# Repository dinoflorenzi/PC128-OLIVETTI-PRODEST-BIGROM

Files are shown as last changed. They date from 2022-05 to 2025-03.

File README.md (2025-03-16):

# PC128-OLIVETTI-PRODEST-BIGROM
## PROJECT OVERVIEW
Questo è un progetto nato per realizzare una cartuccia rom multi pagina per il mio PC 128 OLIVETTI PRODEST HOME COMPUTER.
Ho progettato e costruito due diverse schede ROM basate su due diversi chip ROM.
Una scheda ROM è basata sul chip rom at28c256, la seconda è basata sul chip flash sst39f040.
Inoltre ho codificato le routine ASM 6809 per gestirle.<br/>

## COME E' NATO IL PROGETTO
Molte sono le cartucce rom progettate, ma ho avuto la necessità di progettare la mia versione, con pochi semplici componenti e la possibilità di programmare la rom dal pc128 stesso, senza utilizzare strumenti di programmazione esterni.
Infatti, è possibile caricare l'immagine rom da masterizzare, utilizzando un dispositivo a cassetta o tramite connessione seriale a un PC esterno.<br/>
## PORTA PER CARTUCCE
I computer PC128 dispongono di una porta per cartucce con i segnali principali del computer, bus dati a 8 bit, bus indirizzi a 16 bit, chip select, master clock.<br/>
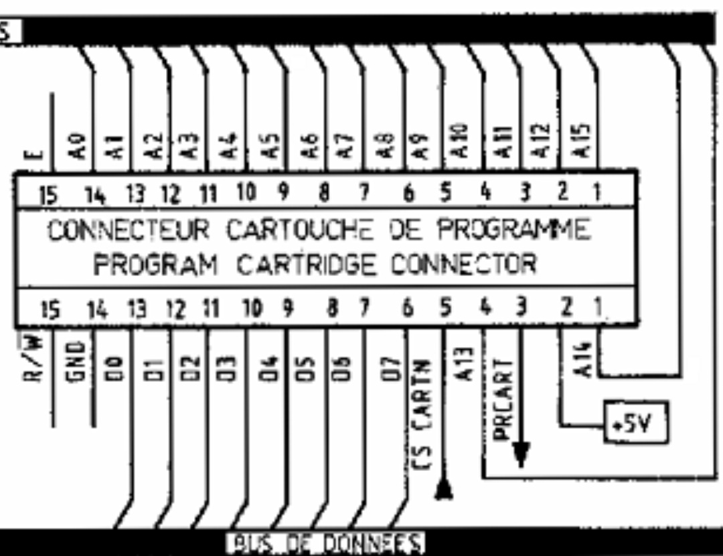
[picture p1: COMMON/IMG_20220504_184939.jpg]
<br/>
## SCELTA DELLE ROM CHIP
La prima selezione di chip AT28C256 si basa sulla sua architettura semplice, bus a 8 bit, indirizzo a 15 bit ed è molto semplice da programmare. Un altro buon motivo è che avevo 3 componenti di riserva nel mio cassetto :)
La selezione del secondo chip SST39F040 si basa anche sul suo package (DIP32), sulla tecnologia pth, sul bus a 8 bit, e soprattutto sulla sua dimensione di 512 kbyte che permette di commutare tra 32 pagine da 16 kbyte ciascuna.
Gli sviluppi della scheda singola sono meglio descritti nei link sottostanti o nella sezione wiki<br/>

[CARTUCCIA A PAGINA SINGOLA](https://github.com/dinoflorenzi/PC128-OLIVETTI-PRODEST-BIGROM/wiki/Single-Page-Rom)<br/>
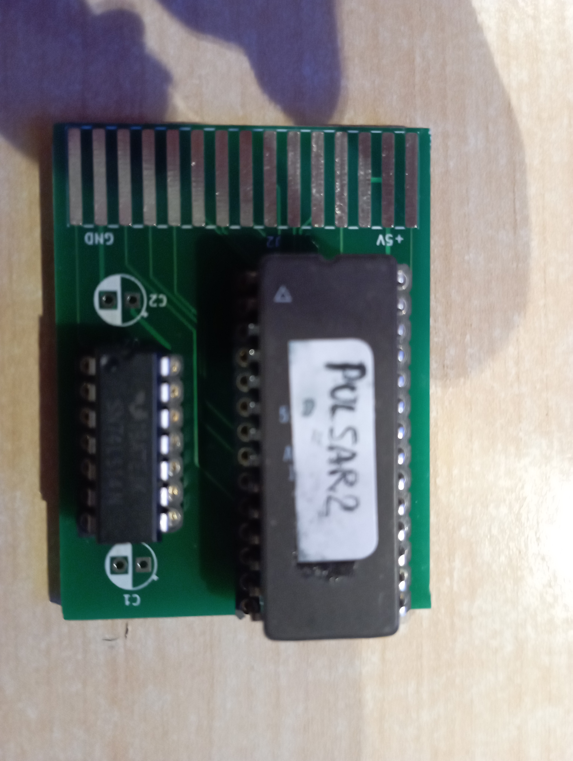
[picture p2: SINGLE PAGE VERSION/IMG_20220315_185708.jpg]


[BIGROM](https://github.com/dinoflorenzi/PC128-OLIVETTI-PRODEST-BIGROM/wiki/BigRom)<br/>
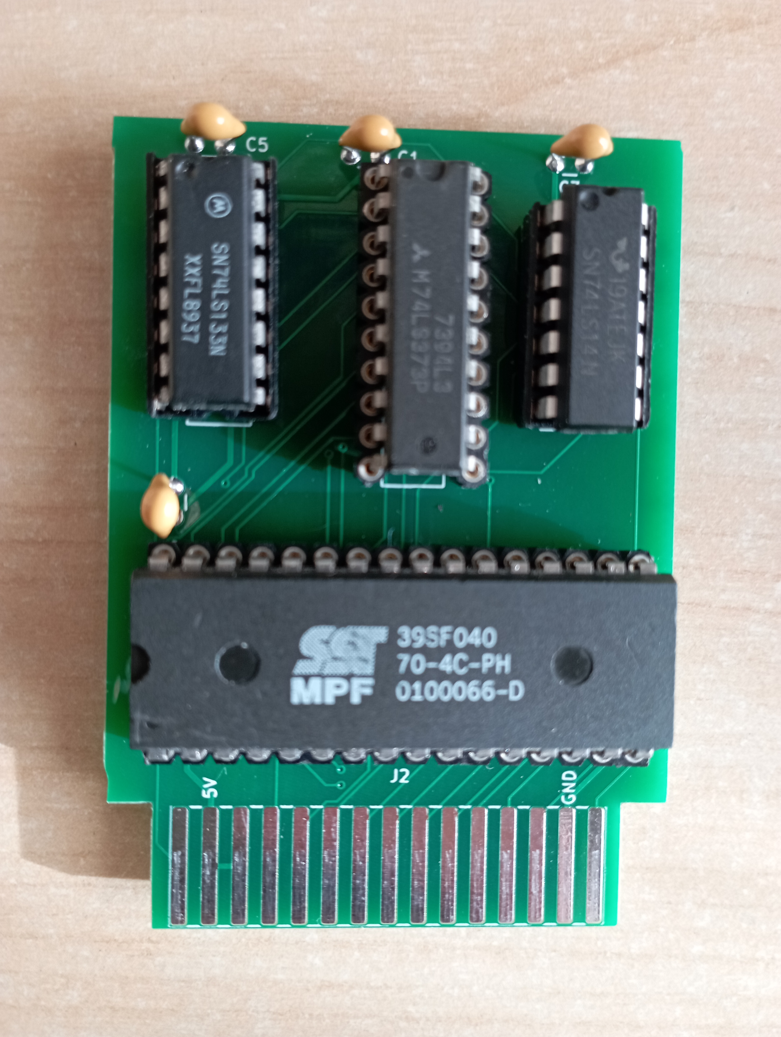
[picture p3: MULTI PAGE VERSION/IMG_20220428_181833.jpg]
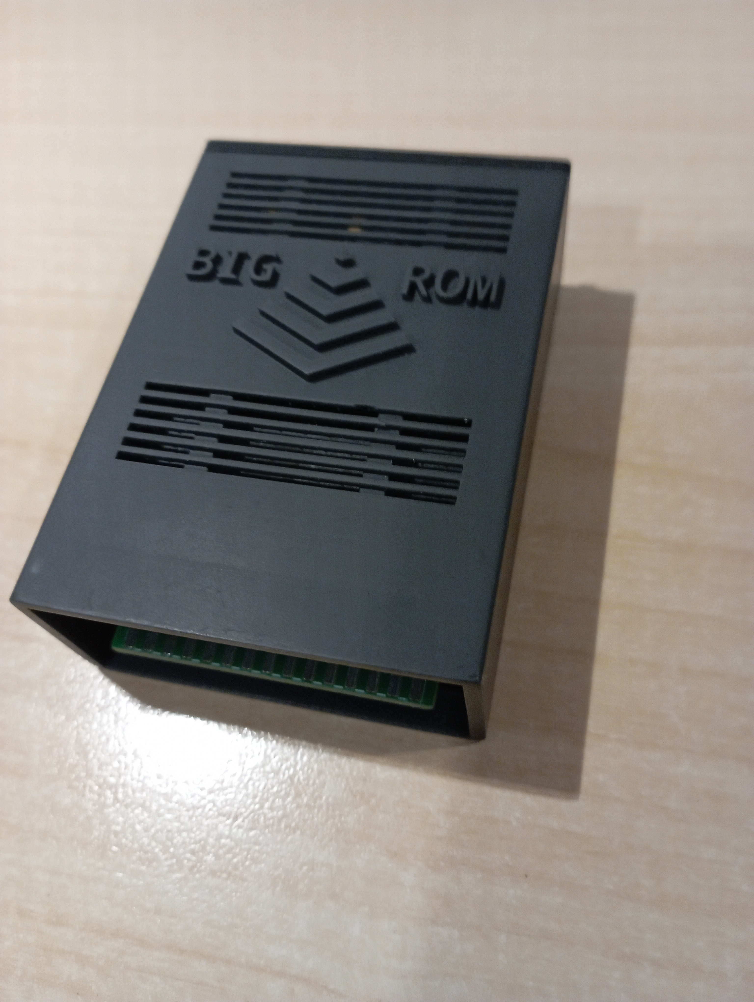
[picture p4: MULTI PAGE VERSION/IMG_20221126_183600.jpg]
 

### INSTALLAZIONE DELLA BIGROM
La cartuccia si installa nello sportellino centrale del PC128, a computer spento, come mostrato nella foto<br/>
Per l' installazione del software di gestione della bigrom è possibile utilizzare un programmatore utilizzando il file bigrom.eeprom, in tal caso la flash deve essere programmata prima dell' installazione sulla scheda. Altrimenti è possibile caricare il programma di gestione da registratore utilizzando un'audiocassetta su cui deve essere registrato il file audio bigrom.k7.wav. Dopodiché da basic 128 digitare<br/>
CLEAR,&H2FFF<br/>
LOADM"CASS:",,R<br/>
A questo punto sarà possibile caricare il file bigrom.rom in posizione V che è la posizione di boo.</br>
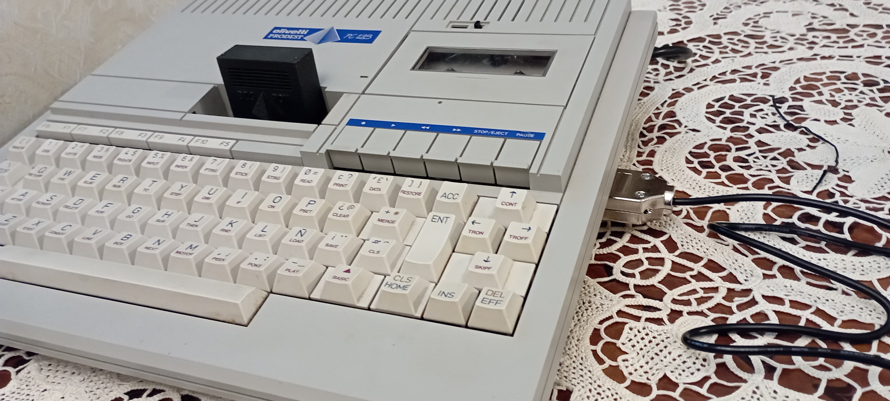
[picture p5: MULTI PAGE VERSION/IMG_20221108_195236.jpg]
<br/>

### FILE MANAGER DELLA BIGROM
Una delle 32 pagine della Bigrom è dedicata al programma di gestione della Bigrom stessa.
La schermata principale visualizza l'elenco dei programmi contenuti nella Bigrom. Basta premere il relativo tasto per scegliere la ROM.
Una volta avviata la ROM per tornare al programma BIGROM bisogna spegnere e riaccendere il computer.<br/>
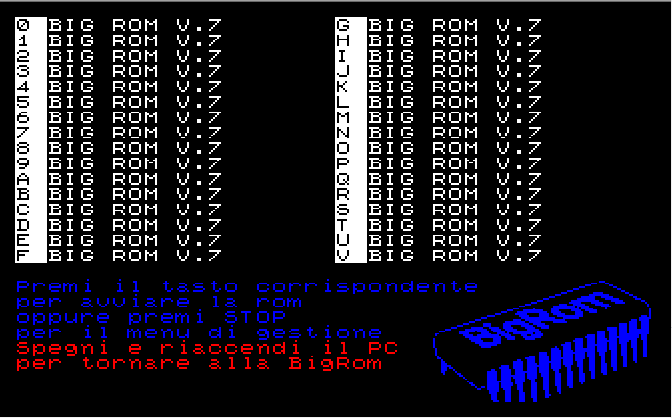
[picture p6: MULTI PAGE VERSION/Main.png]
<br/>
Premendo il tasto STOP dal menu di scelta delle ROMS si entra nel menu di gestione della ROM.<br/>
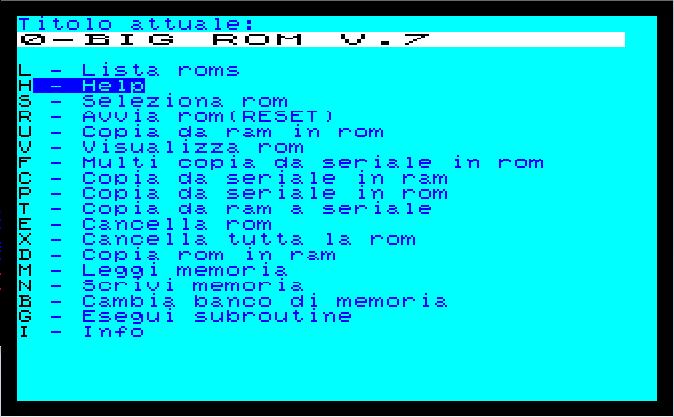
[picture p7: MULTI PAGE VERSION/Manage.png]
<br/>

### CONNESSIONE SERIALE
La connessione seriale sfrutta un UART-USB adapter, che connette il PC128 ad un computer con sistema opperativo windows.
Per il funzionamento del cavo seriale sarà necessario installare i [drivers](https://github.com/dinoflorenzi/PC128-OLIVETTI-PRODEST-BIGROM/tree/main/SERIAL-INTERFACE/Software/WIN_DRIVERS).<br/>E' consigliato l' utilizzo dell' interfaccia CH340 per un discorso di compatibilità.<br/>
Il [cavo](https://github.com/dinoflorenzi/PC128-OLIVETTI-PRODEST-BIGROM/wiki/Serial-Cable) si connette alla porta joystick 2 del PC128 e ad una qualsiasi porta USB del computer Windows.<br/>
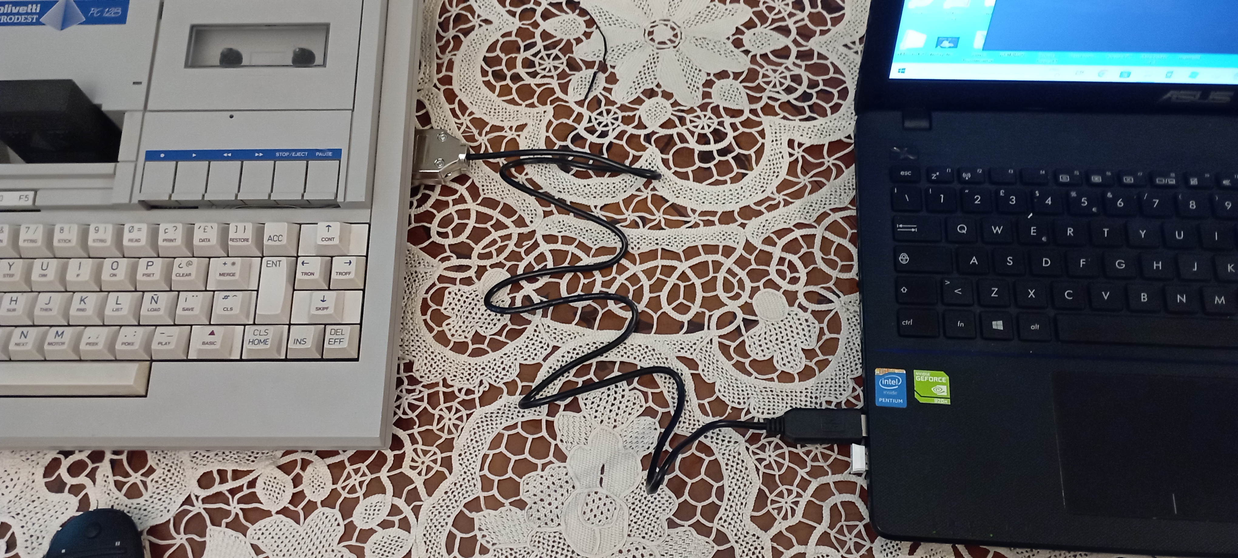
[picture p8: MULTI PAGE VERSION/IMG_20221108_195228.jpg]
<br/><br/>
Dal lato computer Windows si deve avviare il programma [VSerialRomT.exe](https://github.com/dinoflorenzi/PC128-OLIVETTI-PRODEST-BIGROM/blob/main/SERIAL-INTERFACE/Software/VSerialRomT.exe) con il quale si potranno selezionare le roms da caricare, nell'ordine in cui sono inserite, dopodichè premere LOAD. Il programma si mette in attesa del PC128.<br/>
Dal lato PC128 bisogna entrare nel menu di gestione premendo STOP, poi premere F per il caricamento multiplo e successivamente confermare la scelta .<br/> 
Attenzione se non si dispone dello spazio, verranno caricate solamente le ROMS negli spazi vuoti. L'alternativa è cancellare le ROMS non utilizzate.<br/>
#### ATTENZIONE!!!! la posizione del programma di gestione della BIGROM non deve essere cambiato.<br/>
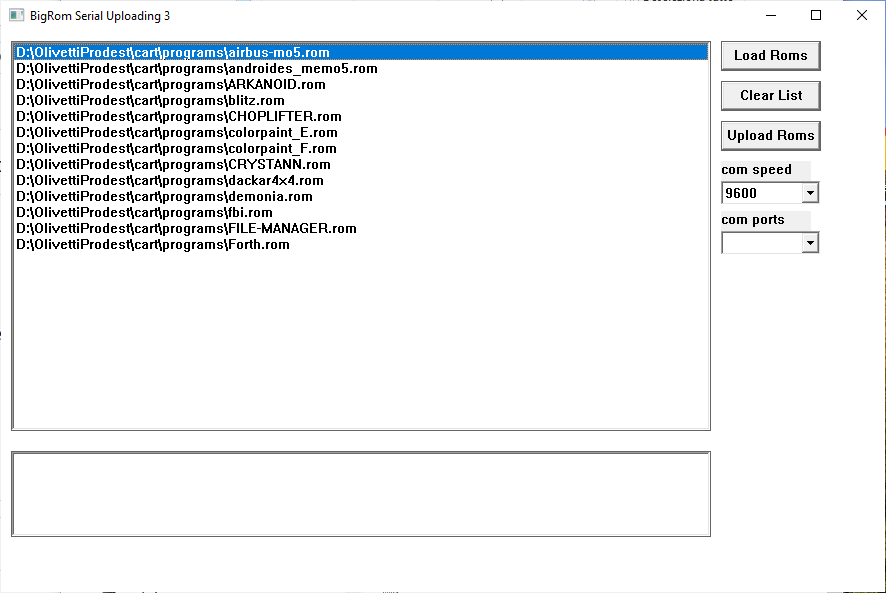
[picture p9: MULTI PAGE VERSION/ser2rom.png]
<br/><br/>
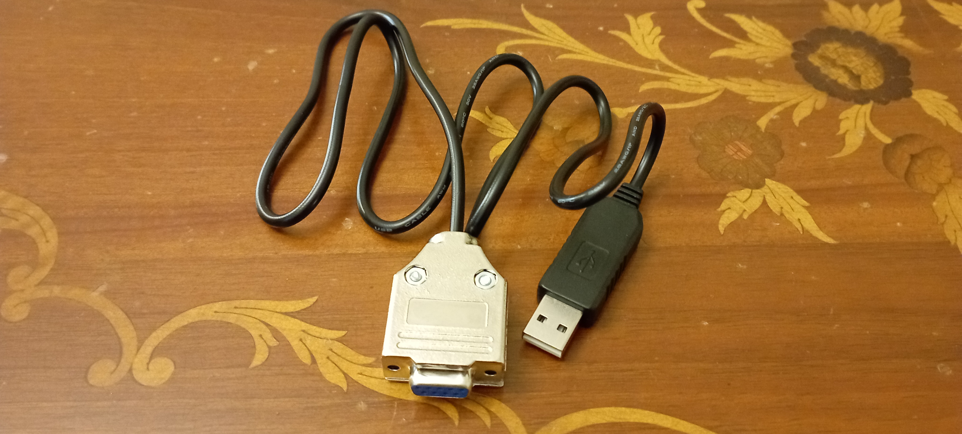
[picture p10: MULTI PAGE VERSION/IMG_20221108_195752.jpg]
<br/><br/>

## VIDEO DEMO
Below, a demostrating videos.<br/>
IMAGE ALT TEXT HERE (https://youtu.be/s6rl8qWxTY4)
IMAGE ALT TEXT HERE (https://youtu.be/AeOjjLHGntw)
## SVILUPPI FUTURI 
Sincronizzazione del contenuto della Bigrom con il programma di caricamento e gestione drag&drop.
Incremento della velocità della seriale.
Esecuzione di programmi in basic.
## SOFTWARE TOOLS
[Kicad](https://www.kicad.org/) and [Freerounting](https://freerouting.org/) to develop schematics and pcb.<br/>
[CMOC](http://perso.b2b2c.ca/~sarrazip/dev/cmoc.html) C compiler to develop page 0 Rom Tool.

## DOVE TROVARE LE ROMS
https://github.com/dinoflorenzi/PC128-OLIVETTI-PRODEST-BIGROM/tree/main/ROMS
http://dcmoto.free.fr/programmes/_html/support_memo5.html
https://www.6502man.com/Bricolages/MEMO5_multirom/MEMO5_multirom.html
## RESOURCES
http://dcmoto.free.fr/documentation/schemas/mo6.png
https://www.mouser.it/datasheet/2/268/doc0006-1108095.pdf
https://www.mouser.it/datasheet/2/268/39%20Series_MPF_MPF__Product%20Brief-373259.pdf

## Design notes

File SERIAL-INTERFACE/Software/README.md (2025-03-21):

## rom22eeprom.exe 
Converte i file .rom caricabili da PC128 in file .eeprom caricabili da programmatore e viceversa.
Specificare il nome file che sarà convertito in base all' estensione.

## SerialRom.exe 
windows console program to load roms to PC128 by dedicated serial cable. Copy this program with the roms to C:cart folder.

## SerialRomRX.exe
windows console program to download the roms from PC128 to wondows PC by dedicated serial cable. Copy this program to C:cart folder.

## VSerialRomT.exe
windows style program with friendly interface to load roms to PC128 by dedicated serial cable. Copy this program to your favourite folder.

## uart_rx.asm
asm code to serial receiving.

## uart_tx.asm
asm code to serial transmitting.

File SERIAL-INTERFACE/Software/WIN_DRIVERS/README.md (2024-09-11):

For prolific PL2303 serial-interface adapter use this driver and avoid driver update. The last drivers don't work.

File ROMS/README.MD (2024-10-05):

Le ROMS che hanno il nome file che finisce con una lettera,vanno installate obbligatoriamente nella posizione indicata dalla lettera.

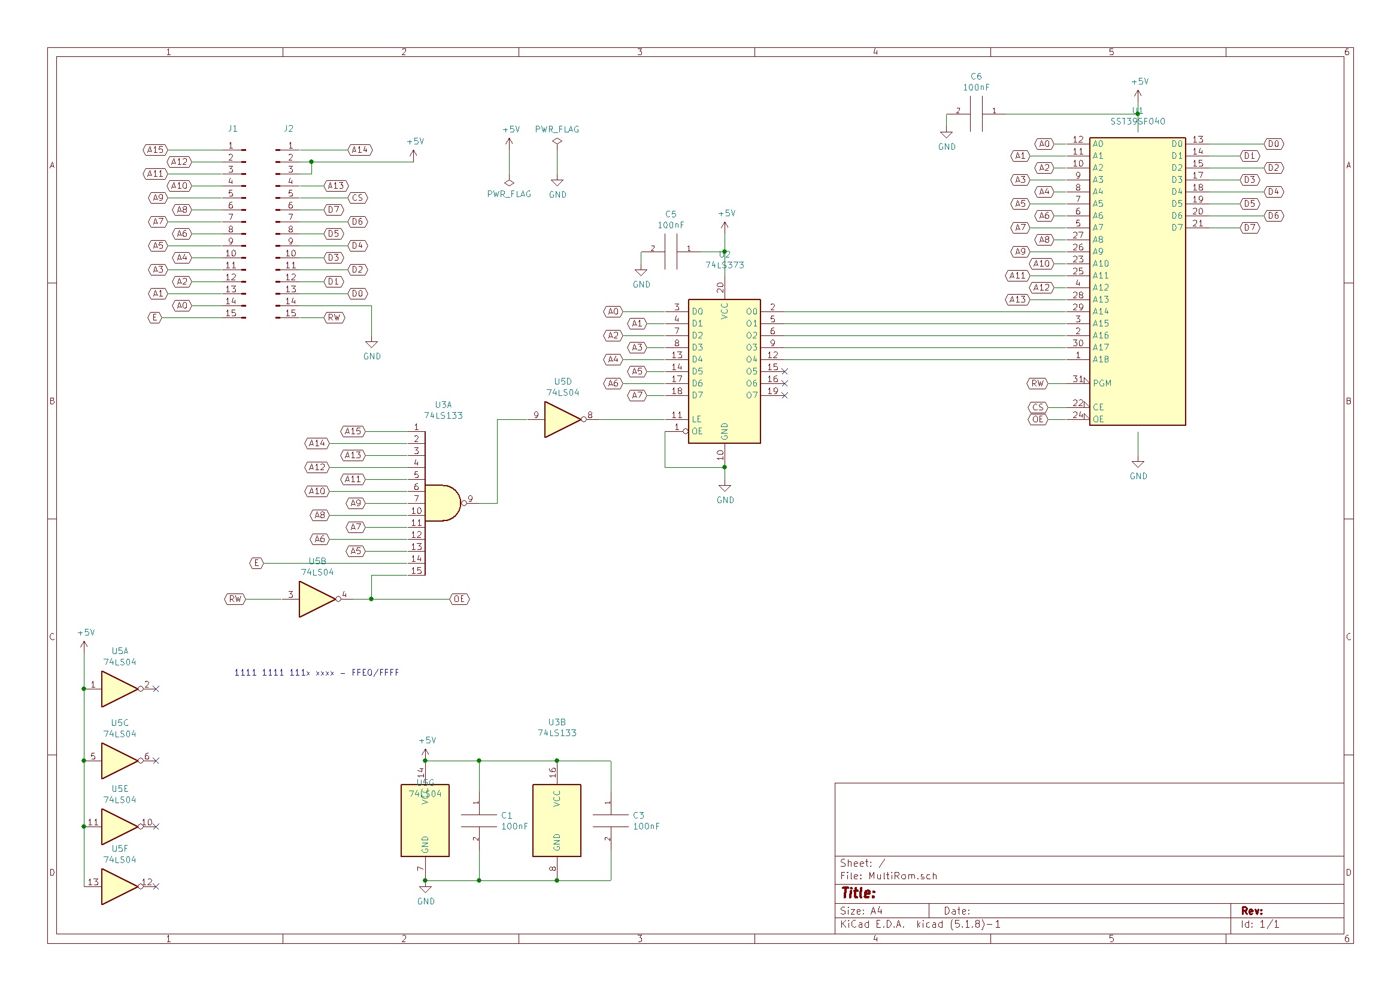
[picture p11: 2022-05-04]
MULTI PAGE VERSION/Schematic.jpg

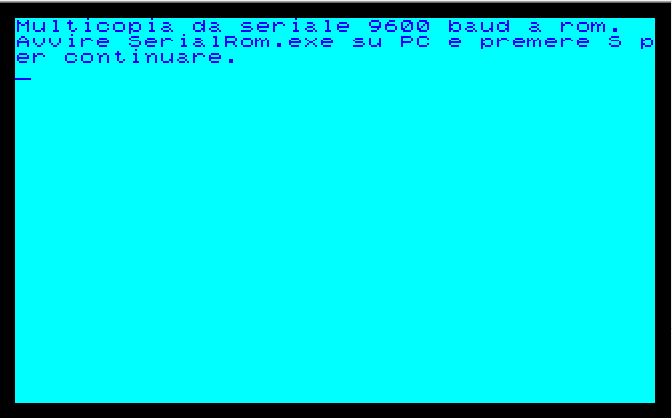
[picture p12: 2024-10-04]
MULTI PAGE VERSION/Upload.png

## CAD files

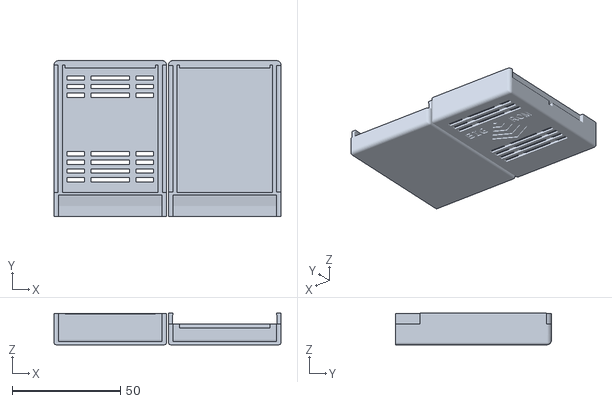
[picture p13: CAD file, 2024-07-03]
MULTI PAGE VERSION/Case/modello_3d/case_incastro.stl
104.9 x 72.0 x 14.6

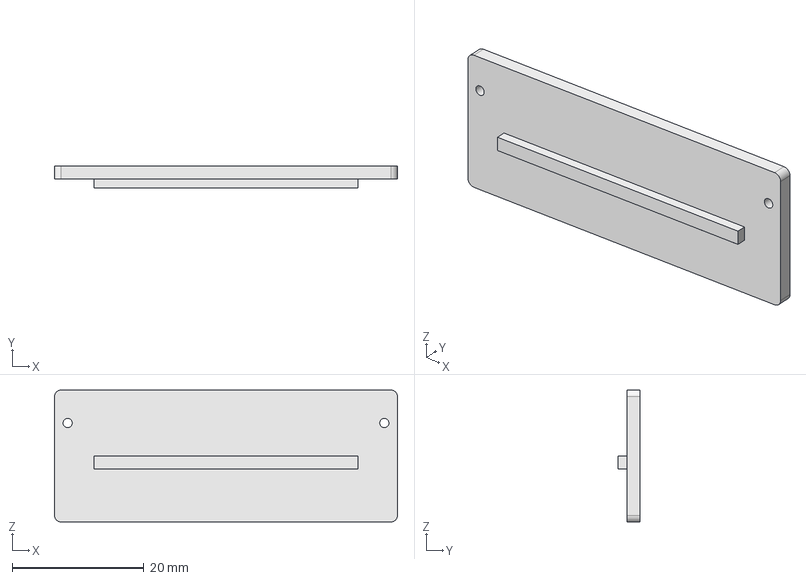
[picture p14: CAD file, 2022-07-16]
MULTI PAGE VERSION/Case/modello_3d/Progetto_Freecad/coperchio.FCStd
52.0 x 3.40 x 20.0 mm

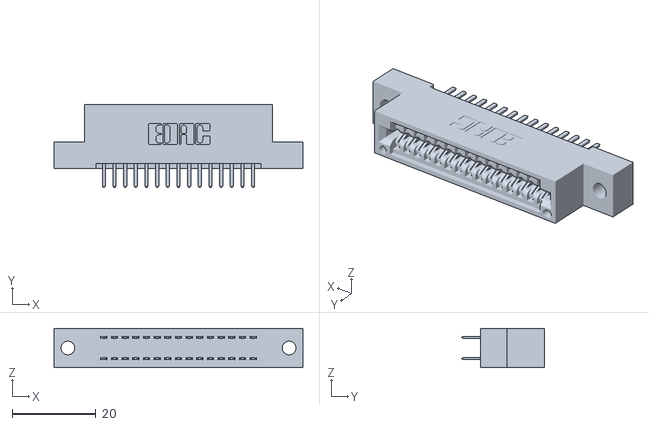
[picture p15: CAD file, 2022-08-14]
MULTI PAGE VERSION/Case/modello_3d/Progetto_Fusion360/edgeconnector-Model.stl
59.3 x 19.7 x 9.40

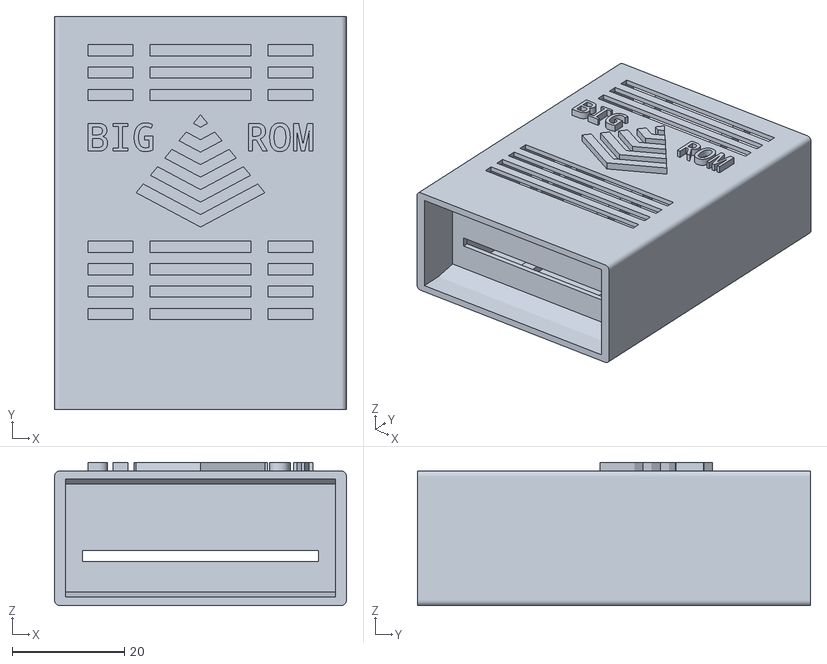
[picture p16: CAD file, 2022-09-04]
MULTI PAGE VERSION/Case/modello_3d/case.stl
52.0 x 70.0 x 25.5

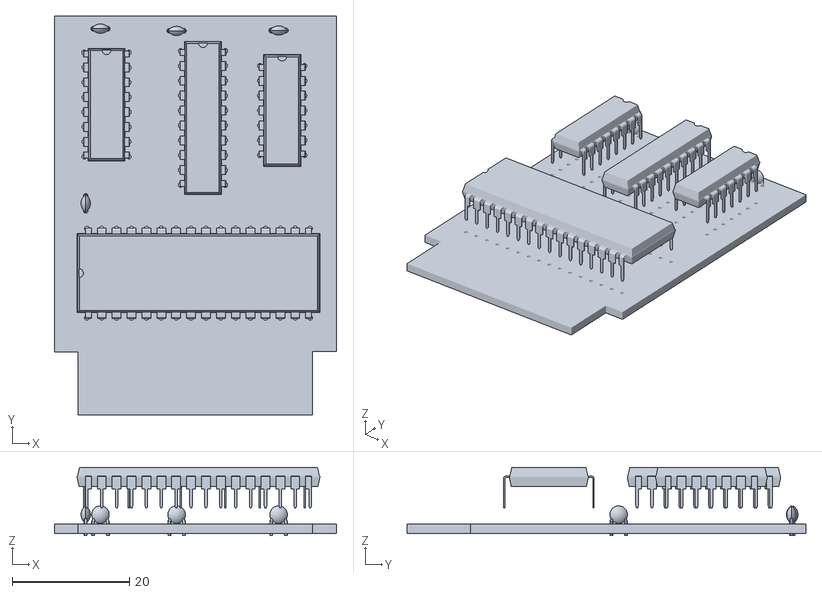
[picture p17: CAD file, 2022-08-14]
MULTI PAGE VERSION/Case/modello_3d/Progetto_Fusion360/pcb-MultiRom.stl
48.1 x 68.1 x 11.7

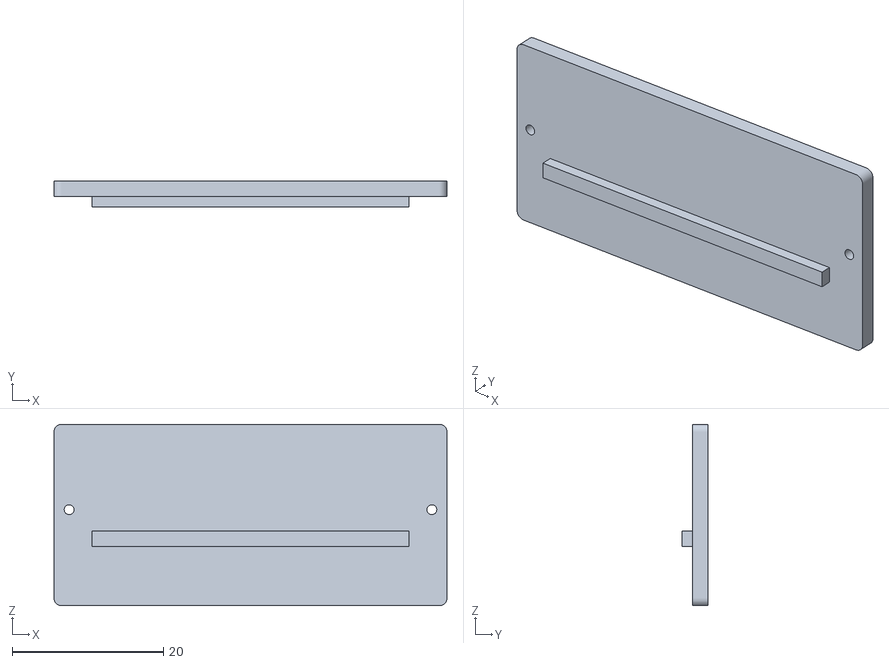
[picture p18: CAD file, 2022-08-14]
MULTI PAGE VERSION/Case/modello_3d/coperchio.stl
52.0 x 3.40 x 24.0

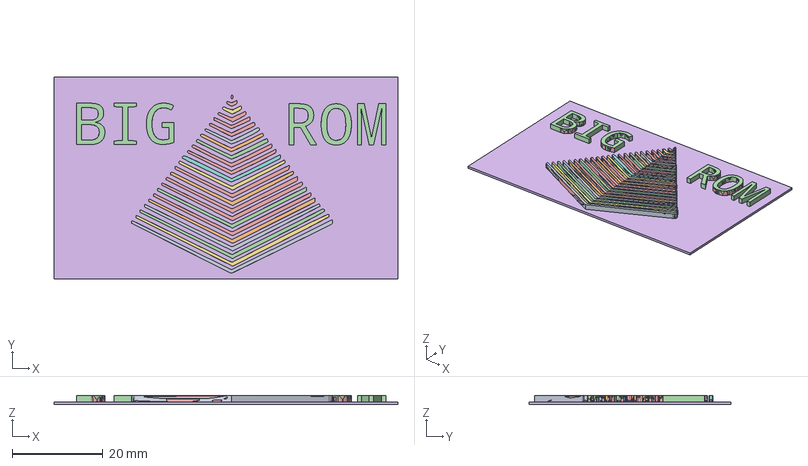
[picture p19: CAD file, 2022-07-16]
MULTI PAGE VERSION/Case/modello_3d/Progetto_Freecad/logo.FCStd
75.9 x 44.6 x 2.00 mm

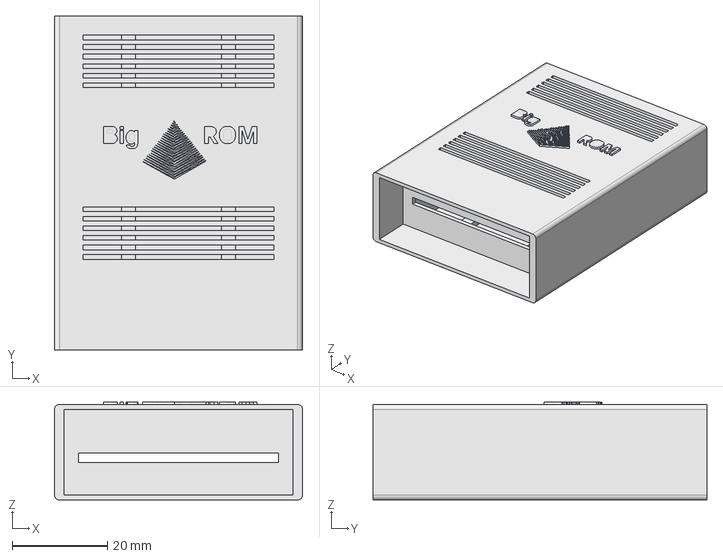
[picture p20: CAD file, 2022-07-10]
MULTI PAGE VERSION/Case/modello_3d/box.FCStd
52.0 x 70.0 x 20.5 mm
Fillet_arrotondamentospigoli
Fusion_caselogo

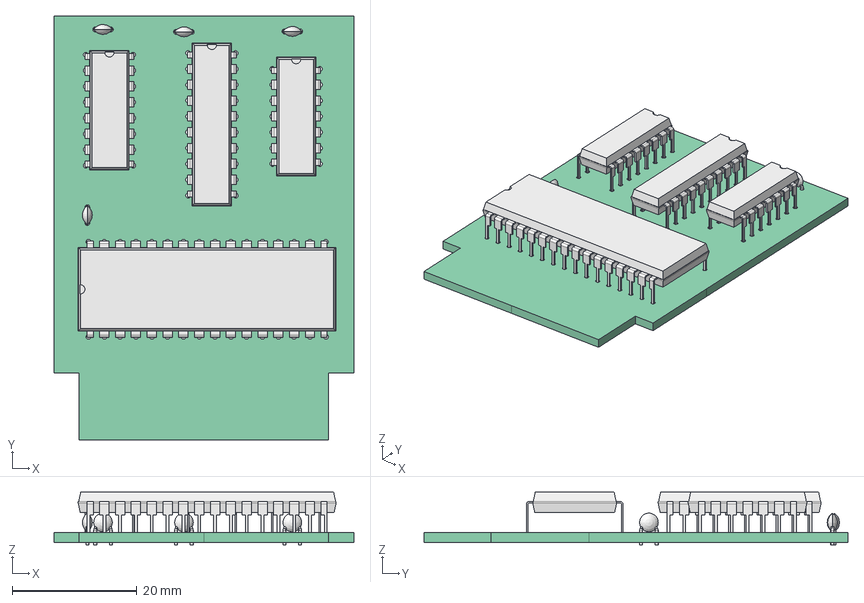
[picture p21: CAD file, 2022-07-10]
MULTI PAGE VERSION/Case/modello_3d/Progetto_Freecad/pcb.FCStd
48.1 x 68.1 x 8.48 mm
U1_DIP-32_W15.24mm_0000621698e7
U2_DIP-20_W7.62mm_00006216990f
U3_DIP-16_W7.62mm_000062169935
C1_C_Disc_D30mm_W16mm_P250mm_00006216c3a7 x 4
U5_DIP-14_W7.62mm_0000625470de
Pcb_a11d

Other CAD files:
MULTI PAGE VERSION/Case/modello_3d/Progetto_Freecad/assembly.FCStd
MULTI PAGE VERSION/Case/modello_3d/Progetto_Freecad/edgeconnector.FCStd
MULTI PAGE VERSION/Case/modello_3d/Progetto_Fusion360/case.f3d
MULTI PAGE VERSION/Case/modello_3d/case_incastro.f3d

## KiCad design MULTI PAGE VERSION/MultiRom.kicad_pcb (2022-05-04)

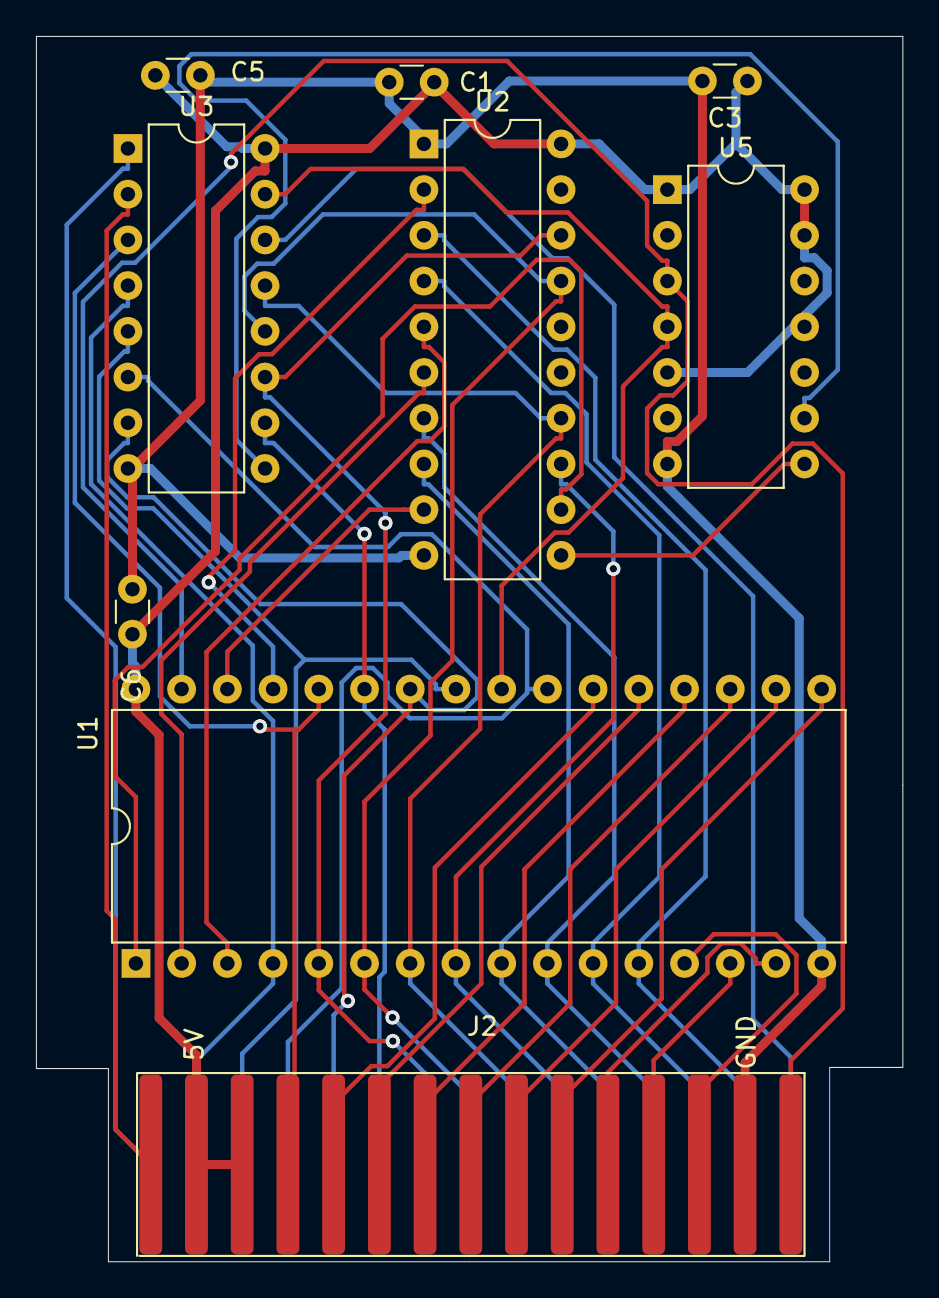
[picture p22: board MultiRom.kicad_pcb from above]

Board: 2 copper layers, 48.1 x 68.1 mm, 10 parts (1 on the bottom side), 37 nets.

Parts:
C1, C3, C5, C6: 100nF; C_Disc_D3.0mm_W1.6mm_P2.50mm
J1, J2: Conn_01x15_Male; EdgeConn_15
U1: SST39SF040; DIP-32_W15.24mm
U2: 74LS373; DIP-20_W7.62mm
U3: 74LS133; DIP-16_W7.62mm
U5: 74LS04; DIP-14_W7.62mm

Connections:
+5V: C1.1, C3.1, C5.1, C6.1, J2.2, J2.3, U1.32, U2.20, U3.16, U5.1, U5.5, U5.11, U5.13, U5.14
A0: J1.14, U1.12, U2.3
A1: J1.13, U1.11, U2.4
A2: J1.12, U1.10, U2.7
A3: J1.11, U1.9, U2.8
A4: J1.10, U1.8, U2.13
A5: J1.9, U1.7, U2.14, U3.13
A6: J1.8, U1.6, U2.17, U3.12
A7: J1.7, U1.5, U2.18, U3.11
A8: J1.6, U1.27, U3.10
A9: J1.5, U1.26, U3.7
A10: J1.4, U1.23, U3.6
A11: J1.3, U1.25, U3.5
A12: J1.2, U1.4, U3.4
A13: J2.4, U1.28, U3.3
A14: J2.1, U3.2
A15: J1.1, U3.1
CS: J2.5, U1.22
D0: J2.13, U1.13
D1: J2.12, U1.14
D2: J2.11, U1.15
D3: J2.10, U1.17
D4: J2.9, U1.18
D5: J2.8, U1.19
D6: J2.7, U1.20
D7: J2.6, U1.21
E: J1.15, U3.14
GND: C1.2, C3.2, C5.2, C6.2, J2.14, U1.16, U2.1, U2.10, U3.8, U5.7
unnamed: U1.1, U2.12
unnamed: U1.2, U2.6
unnamed: U1.3, U2.5
unnamed: U1.29, U2.2
unnamed: U1.30, U2.9
unnamed: U2.11, U5.8
unnamed: U3.9, U5.9
OE: U1.24, U3.15, U5.4
RW: J2.15, U1.31, U5.3

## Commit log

2022-07-10 Modello 3D case
    [assembly.FCStd, box.FCStd, coperchio.FCStd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]
2022-07-16 fix modelli STL per stampa 3D - modificato logo - modificata svasatura viti
    [assembly.FCStd, coperchio.FCStd, coperchio.stl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]
2022-08-12 Case rialzato a 24mm Aumentata altezza case e coperchio a 24mm Aumentato spessore parete dal lato del connettore Aggiunto rinforzo lato connettore Vecchio progetto Freecad spostato in cartella a part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
    [assembly.FCStd, case.f3d, case.stl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]
2022-08-14 Aggiornato modello 3D case (multipart)
    [case.f3d, case.stl]
2022-08-19 Fix logo troppo fragile per stampa 3D
    [case.f3d, case.stl]
2022-09-04 Allargato spessore griglie a 2mm Fix per rottura in fase di stampa 3D
    [case.f3d, case.stl]
2023-05-07 USB->UART_Cable Driver PL2303 Chipset
2023-05-07 USB->UART CH340 CHIPSET DRIVER
2024-10-19 Add files via upload
    - baudrate a 19200
    - incrementata velocità di scrittura flash
    - calcolo CRC rom
